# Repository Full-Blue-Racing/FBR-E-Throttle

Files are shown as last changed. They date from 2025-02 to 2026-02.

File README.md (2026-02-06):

# Wiring

# APPS

5V input/output. Use a voltage divider/other approach to condition the analogue output to a range that can be read by ESP32

# TPS

# Nema 23 Stepper motor

https://www.motechmotor.com/productDetail-0105-81.html

step angle $1.8\degree$

# TMC5160 driver board

datasheet: [TMC5160 Datasheet (long))](https://www.analog.com/media/en/technical-documentation/data-sheets/TMC5160A_datasheet_rev1.18.pdf)

Description: [TMC5160 BOB Description](https://www.analog.com/media/en/technical-documentation/data-sheets/tmc5160-bob_datasheet_rev1.10.pdf)

Install this library developed by tommag. both `TMC5160.h` and `Bitfield.h` are included

https://github.com/tommag/TMC5160_Arduino

# Motor torque

Adjust motor torque by writing to these registers (in setup, after SPI communication and motor has been initialised):

```
  motor.writeRegister(TMC5160_Reg::GLOBAL_SCALER, 200); //32-255
  motor.writeRegister(TMC5160_Reg::IHOLD_IRUN, 0x00011F14);
```

The complete list of register can be found in /TMC5160_registers.h

The `IHOLD_IRUN` register format:

* Bits 0-4: ihold (in this case hex(14) = dec(20))(0-31) (set to <= 70% of irun)
* Bits 8-12: irun (0-31)
* Bits 16-19: iholddelay

! For some reasons changing motorParams didn't work for me. had to write to register for the change to stick

## Resources

- [PID Controller in C](https://deepbluembedded.com/esp32-timers-timer-interrupt-tutorial-arduino-ide/)
- [ESP32 Arduino IDE Timer Interrupts Reference](https://deepbluembedded.com/esp32-timers-timer-interrupt-tutorial-arduino-ide/)

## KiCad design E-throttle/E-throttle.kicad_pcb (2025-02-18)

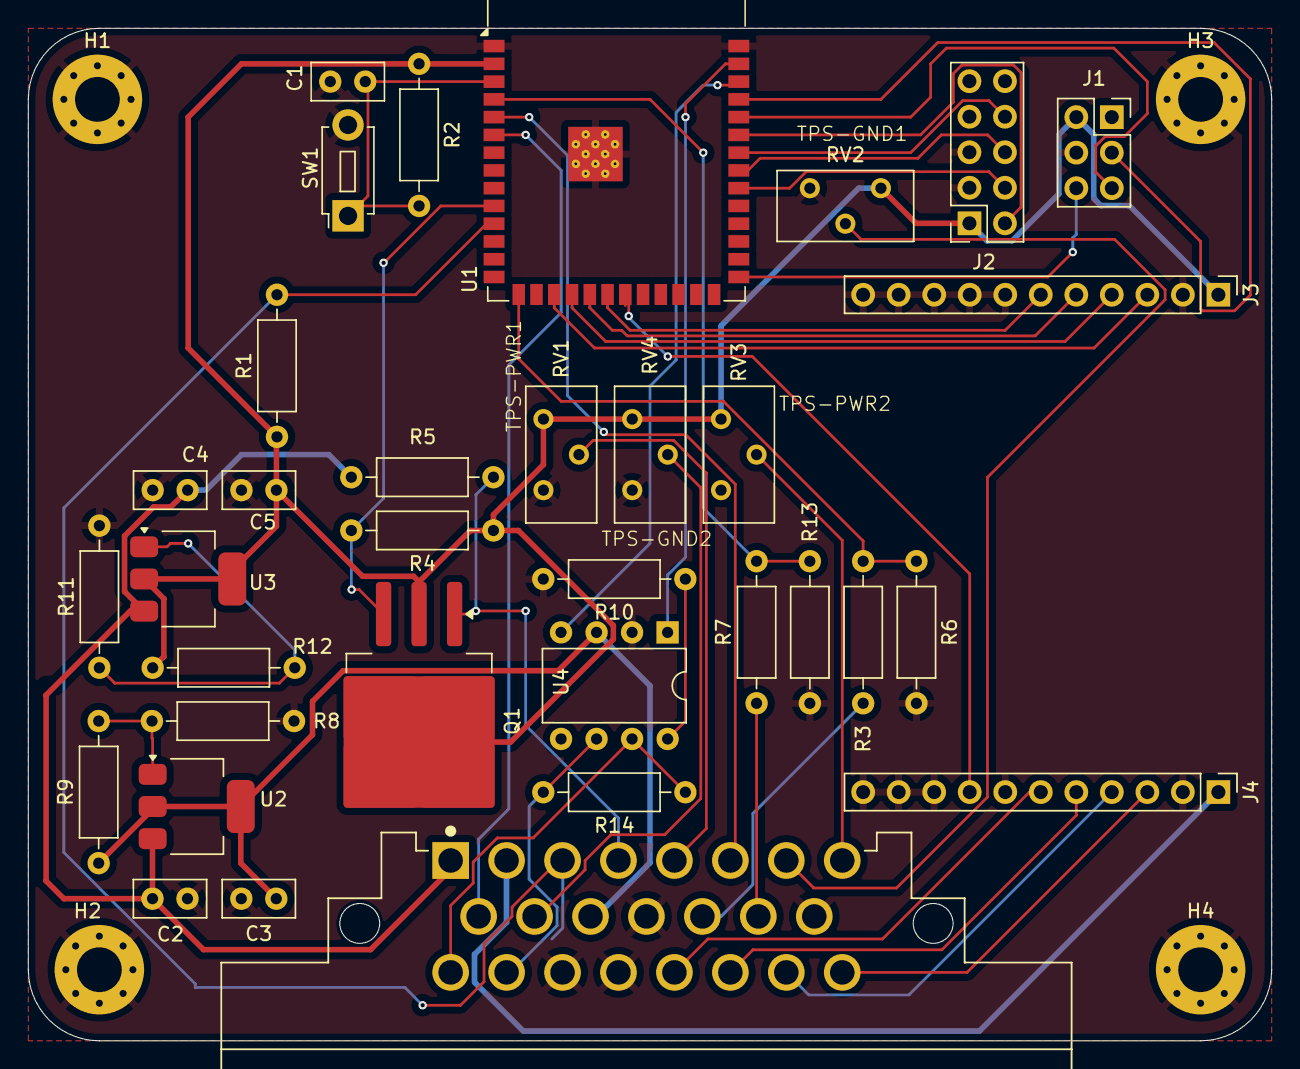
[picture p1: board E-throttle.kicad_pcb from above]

Board: 2 copper layers, 88.9 x 72.4 mm, 38 parts (0 on the bottom side), 42 nets.

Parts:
C1, C3, C5: 1u; C_Disc_D5.0mm_W2.5mm_P2.50mm
C2, C4: 0.1u; C_Disc_D5.0mm_W2.5mm_P2.50mm
H1, H2, H3, H4: MountingHole_Pad; MountingHole_3.2mm_M3_Pad_Via
J1: PROG; PinSocket_2x03_P2.54mm_Vertical
J2: JTAG; PinSocket_2x05_P2.54mm_Vertical
J3, J4: Conn_01x11; PinHeader_1x11_P2.54mm_Vertical
J5: 776087-1; TE_776087-1
Q1: NMOS; TO-263-3_TabPin2
R1: 100k; R_Axial_DIN0207_L6.3mm_D2.5mm_P10.16mm_Horizontal
R2: 10k; R_Axial_DIN0207_L6.3mm_D2.5mm_P10.16mm_Horizontal
R3, R7: 33.2k; R_Axial_DIN0207_L6.3mm_D2.5mm_P10.16mm_Horizontal
R4, R5: R_Small; R_Axial_DIN0207_L6.3mm_D2.5mm_P10.16mm_Horizontal
R6, R13: 66.5k; R_Axial_DIN0207_L6.3mm_D2.5mm_P10.16mm_Horizontal
R8: 715; R_Axial_DIN0207_L6.3mm_D2.5mm_P10.16mm_Horizontal
R9, R12: 240; R_Axial_DIN0207_L6.3mm_D2.5mm_P10.16mm_Horizontal
R10: 20k; R_Axial_DIN0207_L6.3mm_D2.5mm_P10.16mm_Horizontal
R11: 392; R_Axial_DIN0207_L6.3mm_D2.5mm_P10.16mm_Horizontal
R14: 120; R_Axial_DIN0207_L6.3mm_D2.5mm_P10.16mm_Horizontal
RV1, RV2, RV3, RV4: 100k; Potentiometer_Bourns_3296Y_Vertical
SW1: SW_Push; SW_PUSH_1P1T_6x3.5mm_H4.3_APEM_MJTP1243
U1: ESP32-S3-WROOM-1-N16R8; ESP32-S3-WROOM-1
U2, U3: LM317_SOT-223; SOT-223-3_TabPin2
U4: MCP2551-I-P; DIP-8_W7.62mm

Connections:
+3V3: C5.1, J1.2, J2.1, J3.1, Q1.2 (G), R1.1, R2.1, R4.1, R12.1, RV1.1, RV2.1, RV3.1, RV4.1, U1.2 (3V3), U3.2 (VO)
+5V: C3.1, J5.11, R9.1, U2.2 (VO), U4.3 (VDD)
+12V: C2.1, C4.1, J5.1, R5.1, U2.3 (VI), U3.3 (VI)
+12VStep: J4.1, J5.2
/APPS-SIG1: J5.13, R3.1
/APPS-SIG1-OUT: R3.2, R6.1, U1.15 (IO3)
/APPS-SIG2: J5.14, R7.1
/APPS-SIG2-OUT: R7.2, R13.1, U1.4 (IO4)
/BLIP-IN: J5.4, Q1.1 (D), R5.2
/BLIP-OUT: Q1.3 (S), R4.2, U1.10 (IO17)
/BOOTOPT: J1.6, U1.27 (IO0)
/CAN-H: J5.16, R14.1, U4.7 (CANH)
/CAN-L: J5.17, R14.2, U4.6 (CANL)
/CAN_RX: U1.38 (IO2), U4.4 (RXD)
/CAN_TX: U1.39 (IO1), U4.1 (TXD)
/DIAG0: J4.8, U1.21 (IO13)
/ENABLE: C1.1, R2.2, SW1.1, U1.3 (EN)
/IDLE: J5.3, R1.2, U1.11 (IO18)
/JTAG_TCK: J2.4, U1.32 (IO39)
/JTAG_TDI: J2.8, U1.34 (IO41)
/JTAG_TDO: J2.6, U1.33 (IO40)
/JTAG_TMS: J2.2, U1.35 (IO42)
/SPI-CS: J3.3, U1.17 (IO9)
/SPI-MISO: J3.6, U1.20 (IO12)
/SPI-MOSI: J3.5, U1.19 (IO11)
/SPI-SCK: J3.4, U1.18 (IO10)
/STEP-1+: J4.6, J5.20
/STEP-1-: J4.5, J5.21
/STEP-2+: J4.4, J5.22
/STEP-2-: J4.3, J5.23
/TPS-GND1: J5.7, RV2.2
/TPS-GND2: J5.10, RV4.2
/TPS-PWR1: J5.5, RV1.2
/TPS-PWR2: J5.8, RV3.2
/TPS-SIG1: J5.6, U1.5 (IO5)
/TPS-SIG2: J5.9, U1.6 (IO6)
/UART_RX: J1.5, U1.36 (RXD0)
/UART_TX: J1.3, U1.37 (TXD0)
GND: C1.2, C2.2, C3.2, C4.2, C5.2, H1.1, H2.1, H3.1, H4.1, J1.4, J2.3, J2.5, J2.7, J2.9, J3.2, J3.7, J3.8, J3.9, J3.10, J3.11, J4.2, J4.7, J4.9, J4.10, J4.11, J5.12, J5.15, J5.18, J5.19, R6.2, R8.2, R10.2, R11.2, R13.2, RV1.3, RV2.3, RV3.3, RV4.3, SW1.2, U1.1 (GND), U1.40 (GND), U1.41 (GND), U4.2 (VSS)
unnamed: R8.1, R9.2, U2.1 (ADJ)
unnamed: R11.1, R12.2, U3.1 (ADJ)
unnamed: R10.1, U4.8 (Rs)

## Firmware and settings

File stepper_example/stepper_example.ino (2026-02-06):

/*
Connections:
  MOSI (Teensy : 11)  <=> SDI
  MISO (Teensy : 12)  <=> SDO
  SCK (Teensy : 13)   <=> SCK
  5                   <=> CSN
  8                   <=> DRV_ENN (optional, tie to GND if not used) - not used in testing last time
  GND                 <=> GND
  3.3V/5V             <=> VCC_IO (depending on the processor voltage)

The TMC5160 VS pin must also be powered.
Tie CLK16 to GND to use the TMC5160 internal clock.
Tie SPI_MODE to VCC_IO, SD_MODE to GND.
*/


#include <ArxTypeTraits.h>

#include <Bitfield.h>
#include <TMC5160.h>
#include <TMC5160_registers.h>

#include <Arduino.h>
#include <SPI.h>


const uint8_t SPI_CS = 5; // CS pin in SPI mode
//const uint8_t SPI_DRV_ENN = 8;  // DRV_ENN pin in SPI mode

TMC5160_SPI motor = TMC5160_SPI(SPI_CS); //Use default SPI peripheral and SPI settings.


void setup()
{
  // USB/debug serial coms
  Serial.begin(115200);

  //pinMode(SPI_DRV_ENN, OUTPUT); 
  //digitalWrite(SPI_DRV_ENN, LOW); // Active low

  // This sets the motor & driver parameters /!\ run the configWizard for your driver and motor for fine tuning !
  TMC5160::PowerStageParameters powerStageParams; // defaults.
  TMC5160::MotorParameters motorParams;


  SPI.begin();
  motor.begin(powerStageParams, motorParams, TMC5160::NORMAL_MOTOR_DIRECTION);
  motorParams.globalScaler = 255; // Adapt to your driver and motor (check TMC5160 datasheet - "Selecting sense resistors")
  motorParams.irun = 31;
  motorParams.ihold = 20;
  motor.writeRegister(TMC5160_Reg::GCONF, 0x00000004);
  motor.writeRegister(TMC5160_Reg::GLOBAL_SCALER, 200);
  motor.writeRegister(TMC5160_Reg::IHOLD_IRUN, 0x00011F14);
  // ramp definition
  motor.setRampMode(TMC5160::POSITIONING_MODE);
  motor.setMaxSpeed(200);
  motor.setAcceleration(300);

  Serial.println("starting up");

  delay(1000); // Standstill for automatic tuning
      
  Serial.println("setup complete ----------");
}

void loop()
{
  uint32_t now = millis();
  static unsigned long t_dirchange, t_echo;
  static bool dir;

  // every n seconds or so...
  if ( now - t_dirchange > 5000 )
  {
    t_dirchange = now;

    // reverse direction
    dir = !dir;
    motor.setTargetPosition(dir ? 200 : 0);  // 1 full rotation = 200s/rev
    //switch between pos 200 and 0 depending on direction
  }

  // print out current position
  if( now - t_echo > 100 )
  {
    t_echo = now;

    // get the current target position
    float xactual = motor.getCurrentPosition();
    float vactual = motor.getCurrentSpeed();
    Serial.print("current position : ");
    Serial.print(xactual);
    Serial.print("\tcurrent speed : ");
    Serial.println(vactual);
    Serial.print("GLOBAL_SCALER: ");
    Serial.println(motor.readRegister(TMC5160_Reg::GLOBAL_SCALER));
    Serial.print("IHOLD_IRUN: ");
    Serial.println(motor.readRegister(TMC5160_Reg::IHOLD_IRUN), HEX);
    Serial.print("GCONF: ");
    Serial.println(motor.readRegister(TMC5160_Reg::GCONF), HEX);
  }
}

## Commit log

2025-01-25 Added Stepper Motor Driver (Not Integrated), Deleted CAN Bus Controller MCP2515
    Added Stepper Motor Driver (Not Integrated),
    Deleted CAN Bus Controller MCP2515
    [E-throttle.kicad_sch]
2025-02-02 Connector Complete
    [E-throttle.kicad_pcb, E-throttle.kicad_sch]
2025-02-02 Schematic Complete
    [E-throttle.kicad_sch]
2025-02-07 Footprint Complete
    [E-throttle.kicad_sch]
2025-02-08 Wiring completed
    [E-throttle.kicad_pcb]
2025-02-18 Completed wiring 2.0
2025-02-18 Add logo and attribution to PCB
    [E-throttle.kicad_pcb]
2026-02-06 adjusted motor torque, updated documentation
